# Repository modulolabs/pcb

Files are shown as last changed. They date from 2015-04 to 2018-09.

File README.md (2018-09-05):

Modulo PCBs
===

This repository contains modulo circuit board schematics and pcb layouts.

Repository Contents
---

* Base/ - Eagle files for the Modulo Base
* Controller/ - Eagle files for the Modulo Controller
* Display/ - Eagle files for the Modulo Display
* Eagle/ - Common eagle files and libraries
* IRRemote/ - Eagle files for the Modulo IR Transceiver
* Joystick/ - Eagle files for the Modulo Joystick
* Knob/ - Eagle files for the Modulo Knob
* MotorDriver/ - Eagle files for Modulo Motor Driver
* Panel/ - Scripts for combining individual eagle boards into panels
* ParticleBase/ - Eagle files for the Modulo Particle Base
* Programmer/ - Eagle files for a board that's used to program other modulo boards
* TempProbe/ - Eagle files for the Modulo Temp Probe

Export
---

To export data for manufacturing:

* Load and run Eagle/Modulo.cam from the eagle cam processor. This will generate files in <Board>/Modulo<Board>RFQ/
* Run the ulp moundsmd.ulp and save the mount files to the same RFQ directory
* Run Eagle/integer-bom.ulp to generate the bom file and save it to the same RFQ directory.

License Information
-------------------
These circuit board designs are release under  [Creative Commons ShareAlike 4.0 International](https://creativecommons.org/licenses/by-sa/4.0/).

Please use, reuse, and modify these files as you see fit. Please maintain attribute to Modulo Labs LLC and release derivative work under the same license.

Distributed as-is; no warranty is given.

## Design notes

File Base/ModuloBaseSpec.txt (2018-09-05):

PCB: .062” (1.6mm) FR4 Lead Free RoHS compliant
Layers: 2
Copper: 1oz
Soldermask: Purple
Silkscreen: White
ENIG
SMD both sides
PTH one side

Space jumpers off of PCB using provided spacers before PTH soldering
Manually attach adhesive rubber feet
Snap in card guides

RoHS compliant assembly
Program mcu using provided jig and atmel studio software
Test board using provided jig and testing procedure

Package board in static shielding bag
Print provided label and apply to bag.
Package in cartons of qty 50 with provided carton label.

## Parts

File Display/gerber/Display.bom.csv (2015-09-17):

Qty | Value | Device | Package | Parts | Description | BOARD | BOM | MANUFACTURER | PARTNUM | SUPPLIER | VALUE | VERSION
2 | .1uF | CAPACITOR-.1UF | 0603 | C3, C6 | Capacitor |  |  |  | C0603C104K5RACTU |  | .1uF
1 | 1.33M | RESISTOR-0603 | 0603 | R2 | Resistor |  |  |  | ERJ-3EKF1304V
1 | 10K | RESISTOR-10KΩ | 0603 | R1 | Resistor |  |  |  | ERJ-3EKF1002V |  | 10KΩ
3 | 10KΩ | RESISTOR-10KΩ | 0603 | R3, R5, R6 | Resistor |  |  |  | ERJ-3EKF1002V |  | 10KΩ
4 | 10uF | CAPACITOR-10UF | 0603 | C1, C2, C4, C5 | Capacitor |  |  |  | GRM188R61C106MA73D |  | 10uF
1 | 10uH | INDUCTOR | INDUCTOR_1007 | L1 | Inductors |  |  |  | MPI2520R1-100-R
2 | 1KΩ | RESISTOR-1KΩ | 0603 | R4, R7 | Resistor |  |  |  | ERJ-3EKF1001V |  | 1KΩ
1 | ATSAMD20E17A-AU | SAMD21E | TQFP-32 | U3 |  |  |  |  | ATSAMD20E17A-AU |  | ATSAMD21E18A-AU
1 | BAT54T1G | DIODE-SCHOTTKY | SMP | D1 |  |  |  |  | SS3P3-M3/84A
1 | DEVICE-PCB | DEVICE-PCB | DEVICE-PCB | PCB1 | Modulo Footprint | Display |  |  | Display PCB |  |  | 4
1 | ER-OLED0.95-2C | OLED-COLORREVERSE | FPC-24-REVERSE | U1 |  |  |  | buydisplay.com | ER-OLED0.95-2C | buydisplay.com | ER-OLED0.95-2C
1 | FAN5331SX | FAN5331 | SOT23-5 | U2 | FAN5331 - LED/OLED 20V Boost Converter |  |  |  | FAN5331SX
1 | HEADER-1X4-AMPMODU | HEADER-1X4-AMPMODU | AMPMODU-4P | JP2 |  |  |  |  | 147721-3
1 | MIC5205-3.3YM5 TR | VREG-MIC5205-3.3V | SOT23-5 | U4 | V_REG MIC5219 |  |  |  | MIC5205-3.3YM5 TR |  | MIC5205-3.3YM5 TR
3 | SWITCH-PTS-810 | SWITCH-PTS-810 | TACT-SWITCH-PTS-810 | SW1, SW2, SW3 |  |  |  |  | PTS810 SJM 250 SMTR LFS
1 | blue | LED-0805-BLUE | 0805-LED | LED1 | LED |  |  |  | LTST-C171TBKT |  | blue

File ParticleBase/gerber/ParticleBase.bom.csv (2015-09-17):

Qty | Value | Device | Package | Parts | Description | BOM | NOBOM | PARTNUM | VALUE
1 |  | BOM_ITEM |  | BOM5 |  |  |  | Particle Base PCB
4 |  | M04LOCK | 1X04_LOCK | JP1, JP3, JP5, JP6 | Header 4 |  |  | M20-9750446
1 | 10uF | CAPACITOR-10UF | 0603 | C2 | Capacitor |  |  | GRM188R61C106MA73D | 10uF
2 | 12Ω | RESISTOR-12Ω | 0603 | R3, R4 | Resistor |  |  | ERJ-PA3J120V | 12Ω
1 | 56uF | CAPACITOR-POL-56UF-25V | PANASONIC_D | C1 |  |  |  | EMVA250ADA560MF55G | 56uF
2 | 5kΩ | RESISTOR-5KΩ | 0603 | R1, R2 | Resistor |  |  | ERJ-3EKF5101V | 5kΩ
2 | CARD-GUIDE | CARD-GUIDE | CARD-GUIDE-2 | G1, G3 |  |  |  | HCG-201-165
1 | CARD-GUIDE | CARD-GUIDE | CARD-GUIDE-2 | G2 |  |  |  | HCG-202-165
2 | HEADER-2X18 | HEADER-2X18 | 2X18-LOCK | JP8, JP9 |  |  |  | 12x2 Receptacle
3 | HEADER-MODULO | HEADER-MODULO | JST-PA-SIDE-SMD | JP2, JP4, JP7 |  |  |  | 4P-SMD-2.0-90D
2 | RB751V40 | DIODE-SCHOTTKY-BAT60A | SOD-323 | D1, D2 |  |  |  | RB751V40
1 | SOLDERJUMPERNO | SOLDERJUMPERNO | SJ_2S-NO | SJ1 | Solder Jumper
1 | VREG-MIC5205-3.3V | VREG-MIC5205-3.3V | SOT23-5 | U1 | V_REG MIC5219 |  |  | MIC5205-3.3YM5 TR
4 | foot | BOM_ITEM |  | BOM1, BOM2, BOM3, BOM4 |  |  |  | SJ61A4

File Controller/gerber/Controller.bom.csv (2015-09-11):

Qty | Value | Device | Package | Parts | Description | BOM | PARTNUM | VALUE
3 |  | PINHD-1X6LOCK | 1X06-BIGLOCK | JP3, JP4, JP5 | PIN HEADER |  | M20-9990646
3 | .1uF | CAPACITOR-.1UF | 0603 | C4, C7, C8 | Capacitor |  | C0603C104K5RACTU | .1uF
3 | 10uF | CAPACITOR-10UF | 0603 | C1, C6, C9 | Capacitor |  | GRM188R61C106MA73D | 10uF
1 | 10uH | INDUCTOR-10UH | 0603 | L1 |  |  | BLM18TG102TN1D | 10uH
2 | 18pF | CAPACITOR-18PF | 0603 | C2, C3 | Capacitor |  | C0603C180J5GACTU | 18pF
2 | 1KΩ | RESISTOR-1KΩ | 0603 | R9, R10 | Resistor |  | ERJ-3EKF1001V | 1KΩ
6 | 470Ω | RESISTOR-470Ω | 0603 | R3, R4, R5, R6, R7, R8 | Resistor |  | ERJ-3EKF4700V | 470Ω
1 | 56uF | CAPACITOR-POL-56UF-25V | PANASONIC_D | C5 |  |  | EMVA250ADA560MF55G | 56uF
2 | 5kΩ | RESISTOR-5KΩ | 0603 | R1, R2 | Resistor |  | ERJ-3EKF5101V | 5kΩ
1 | ATSAMD21E18A-AU | SAMD21E | TQFP-32 | U1 |  |  | ATSAMD21E18A-AUT | ATSAMD21E18A-AU
1 | CRYSTAL-AB26TRQ-32.768K | CRYSTAL-AB26TRQ-32.768K | CRYSTAL-AB26TRQ | X1 |  |  | AB26TRQ-32.768KHZ-T
1 | DEVICE-PCB | DEVICE-PCB | DEVICE-PCB | PCB1 | Modulo Footprint |  | Controller PCB
1 | DIODE-SCHOTTKY | DIODE-SCHOTTKY | SMP | D1 |  |  | SS3P3-M3/84A
6 | DIODE-SCHOTTKY-BAT60A | DIODE-SCHOTTKY-BAT60A | SOD-323 | D2, D3, D4, D5, D6, D7 |  |  | RB751V40
1 | HEADER-1X4-AMPMODU | HEADER-1X4-AMPMODU | AMPMODU-4P | JP2 |  |  | 147721-3
1 | M02LOCK | M02LOCK | 1X02_LOCK | JP6 | Standard 2-pin 0.1 header. Use with" |  | M20-9990246
1 | SWITCH-PTS-810 | SWITCH-PTS-810 | TACT-SWITCH-PTS-810 | SW1 |  |  | PTS810 SJM 250 SMTR LFS
1 | USBFCI-MICROB | USBFCI-MICROB | USB-MICROB-FCI | JP1 |  |  | 10118193-0001LF
1 | VREG-MIC5205-3.3V | VREG-MIC5205-3.3V | SOT23-5 | U2 | V_REG MIC5219 |  | MIC5205-3.3YM5 TR
1 | blue | LED-0805-BLUE | 0805-LED | LED1 | LED |  | LTST-C171KRKT | blue
1 | blue | LED-0805-BLUE | 0805-LED | LED2 | LED |  | LTST-C171TBKT | blue

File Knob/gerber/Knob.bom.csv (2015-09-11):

Qty | Value | Device | Package | Parts | Description | BOM | PARTNUM | VALUE
1 | .1uF | CAPACITOR-.1UF | 0603 | C1 | Capacitor |  | C0603C104K5RACTU | .1uF
2 | 0Ω | RESISTOR-0Ω | 0603 | R8, R9 | Resistor |  | ERJ-3GEY0R00V | 0Ω
6 | 150Ω | RESISTOR-150Ω | 0603 | R2, R3, R4, R5, R6, R10 | Resistor |  | ERJ-3EKF1500V | 150Ω
2 | 1KΩ | RESISTOR-1KΩ | 0603 | R1, R7 | Resistor |  | ERJ-3EKF1001V | 1KΩ
1 | ATTINY841 | ATTINY841 | SOIC-14 | U2 |  |  | ATTINY841-SSUR
1 | BOM_ITEM | BOM_ITEM |  | CAP1 |  |  | Knob Cap
1 | DEVICE-PCB | DEVICE-PCB | DEVICE-PCB | PCB1 | Modulo Footprint |  | Knob PCB
1 | HEADER-1X4-AMPMODU | HEADER-1X4-AMPMODU | AMPMODU-4P | JP1 |  |  | 147721-3
1 | LED-1206-REV | LED-1206-REV | LED-1206-REV | LED1 | LED |  | LTST-C230TBKT
1 | TopUp EC12PLRGBSDVBF-D | ENCODER_RGB_CASIDEPADS | ENCODER_LED_3_SIDEPADS | SW1 | Illuminated Rotary Encoder w/ RGB LED and select switch |  | TopUp EC12PLRGBSDVBF-D

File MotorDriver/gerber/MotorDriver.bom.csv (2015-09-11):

Qty | Value | Device | Package | Parts | Description | BOM | PARTNUM | RATING | VALUE
1 |  | M03LOCK_NO_SILK | 1X03_LOCK_NO_SILK | JP2 | Header 3 |  | M20-9990346
1 |  | M063.5MM-6 | SCREWTERMINAL-3.5MM-6 | JP3 | Header 6 |  | OSTTE060104
1 | .1uF | CAPACITOR-.1UF | 0603 | C1 | Capacitor |  | C0603C104K5RACTU |  | .1uF
1 | .1uF | CAPACITOR-.1UF | 0603 | C2 | Capacitor |  | C0603C104K5RACTU | >20V | .1uF
2 | .25Ω | RESISTOR2010 | R2010 | R3, R4 | Resistor |  | CSRN2010FKR250
2 | 0Ω | RESISTOR-0Ω | 0603 | R12, R13 | Resistor |  | ERJ-3GEY0R00V |  | 0Ω
1 | 10uF | CAPACITOR-10UF | 0603 | C4 | Capacitor |  | GRM188R61C106MA73D |  | 10uF
1 | 1KΩ | RESISTOR-1KΩ | 0603 | R1 | Resistor |  | ERJ-3EKF1001V |  | 1KΩ
1 | 56uF | CAPACITOR-POL-56UF-25V | PANASONIC_D | C3 |  |  | EMVA250ADA560MF55G | >20V | 56uF
1 | ATTINY841 | ATTINY841 | SOIC-14 | U3 |  |  | ATTINY841-SSUR
1 | DEVICE-PCB | DEVICE-PCB | DEVICE-PCB | PCB1 | Modulo Footprint |  | Motor Driver PCB
1 | DIODE-SCHOTTKY | DIODE-SCHOTTKY | SMP | D1 |  |  | SS3P3-M3/84A
1 | DRV8848 | DRV8848 | HTSSOP-16 | U2 |  |  | DRV8848PWP
1 | HEADER-1X4-AMPMODU | HEADER-1X4-AMPMODU | AMPMODU-4P | JP1 |  |  | 147721-3
1 | MCP4013 | MCP4013 | SOT-23-6 | U1 |  |  | MCP4013T-503E/CH
1 | RB751V40 | DIODE-SCHOTTKY-BAT60A | SOD-323 | D2 |  |  | RB751V40
1 | blue | LED-0805-BLUE | 0805-LED | LED1 | LED |  | LTST-C171TBKT |  | blue
1 | shunt | BOM_ITEM |  | SHUNT1 |  |  | SPC02SYAN

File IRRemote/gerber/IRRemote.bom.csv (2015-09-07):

Qty | Value | Device | Package | Parts | Description | BOM | PARTNUM | VALUE
1 |  | LED5MM | LED5MM | LED2 | LEDs |  | IR928-6C-F
1 | .1uF | CAPACITOR-.1UF | 0603 | C1 | Capacitor |  | C0603C104K5RACTU | .1uF
5 | 150Ω | RESISTOR-150Ω | 0603 | R2, R3, R4, R5, R6 | Resistor |  | ERJ-3EKF1500V | 150Ω
1 | 1KΩ | RESISTOR-1KΩ | 0603 | R1 | Resistor |  | ERJ-3EKF1001V | 1KΩ
1 | ATTINY841 | ATTINY841 | SOIC-14 | U3 |  |  | ATTINY841-SSUR
1 | DEVICE-PCB | DEVICE-PCB | DEVICE-PCB | PCB1 | Modulo Footprint |  | IRRemote PCB
1 | HEADER-1X4-AMPMODU | HEADER-1X4-AMPMODU | AMPMODU-4P | JP1 |  |  | 147721-3
1 | LED-1206-REV | LED-1206-REV | LED-1206-REV | LED1 | LED |  | LTST-C230TBKT
1 | PNA460XM | PNA460XM | PNA460XM | U1 | IR 38KHz receiver |  | TSOP38338

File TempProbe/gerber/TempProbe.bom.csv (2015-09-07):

Qty | Value | Device | Package | Parts | Description | BOM | PARTNUM | VALUE
2 | .1uF | CAPACITOR-.1UF | 0603 | C1, C2 | Capacitor |  | C0603C104K5RACTU | .1uF
1 | 10KΩ | RESISTOR-10KΩ | 0603 | R1 | Resistor |  | ERJ-3EKF1002V | 10KΩ
1 | 1KΩ | RESISTOR-1KΩ | 0603 | R2 | Resistor |  | ERJ-3EKF1001V | 1KΩ
1 | ATTINY841 | ATTINY841 | SOIC-14 | U2 |  |  | ATTINY841-SSUR
1 | BOM_ITEM | BOM_ITEM |  | HS1 |  |  | F221B1/2 CL210
1 | BOM_ITEM | BOM_ITEM |  | PCB1 |  |  | Temp Probe PCB
1 | TEMP-PROBE | TEMP-PROBE | TEMP_PROBE | PROBE1 |  |  | NTCLE413E2103F102L
1 | blue | LED-0805-BLUE | 0805-LED | LED1 | LED |  | LTST-C171TBKT | blue

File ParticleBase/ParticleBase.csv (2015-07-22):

Qty | Value | Device | Package | Parts | Description | BOM | NOBOM | PARTNUM | VALUE
1 |  | BOM_ITEM |  | BOM5 |  |  |  | Particle Base PCB
4 |  | M04LOCK | 1X04_LOCK | JP1, JP3, JP5, JP6 | Header 4 |  |  | M20-9750446
2 | 1KΩ | RESISTOR-1KΩ | 0603 | R1, R2 | Resistor |  |  | ERJ-3EKF1001V | 1KΩ
1 | 56uF | CAPACITOR-POL-56UF-25V | PANASONIC_D | C1 |  |  |  | EMVA250ADA560MF55G | 56uF
2 | CARD-GUIDE | CARD-GUIDE | CARD-GUIDE-2 | G1, G3 |  |  |  | HCG-201-165
1 | CARD-GUIDE | CARD-GUIDE | CARD-GUIDE-2 | G2 |  |  |  | HCG-202-165
3 | HEADER-1X4-JST-PA-SIDE-SMD | HEADER-1X4-JST-PA-SIDE-SMD | JST-PA-SIDE-SMD | JP2, JP4, JP7 |  |  |  | SM04B-PASS-TBT(LF)(SN)
2 | HEADER-2X18 | HEADER-2X18 | 2X18-LOCK | JP8, JP9 |  |  |  | PPTC182LFBN-RC
4 | foot | BOM_ITEM |  | BOM1, BOM2, BOM3, BOM4 |  |  |  | SJ61A4

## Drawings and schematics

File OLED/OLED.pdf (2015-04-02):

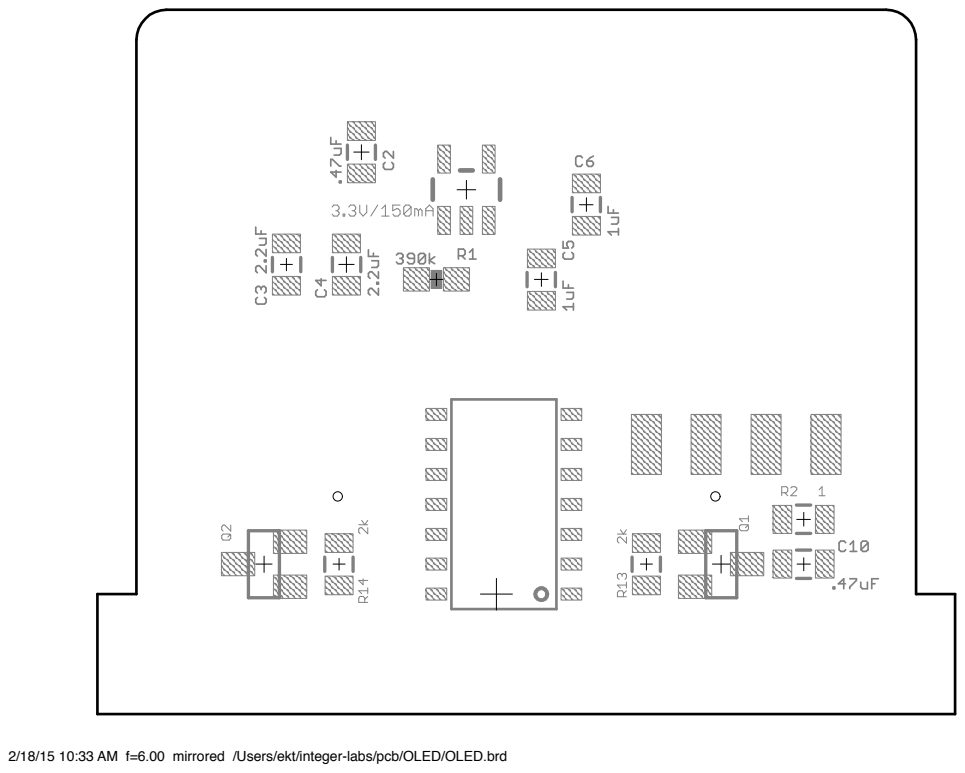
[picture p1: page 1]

2/18/15 10:33 AM f=6.00 mirrored /Users/ekt/integer-labs/pcb/OLED/OLED.brd

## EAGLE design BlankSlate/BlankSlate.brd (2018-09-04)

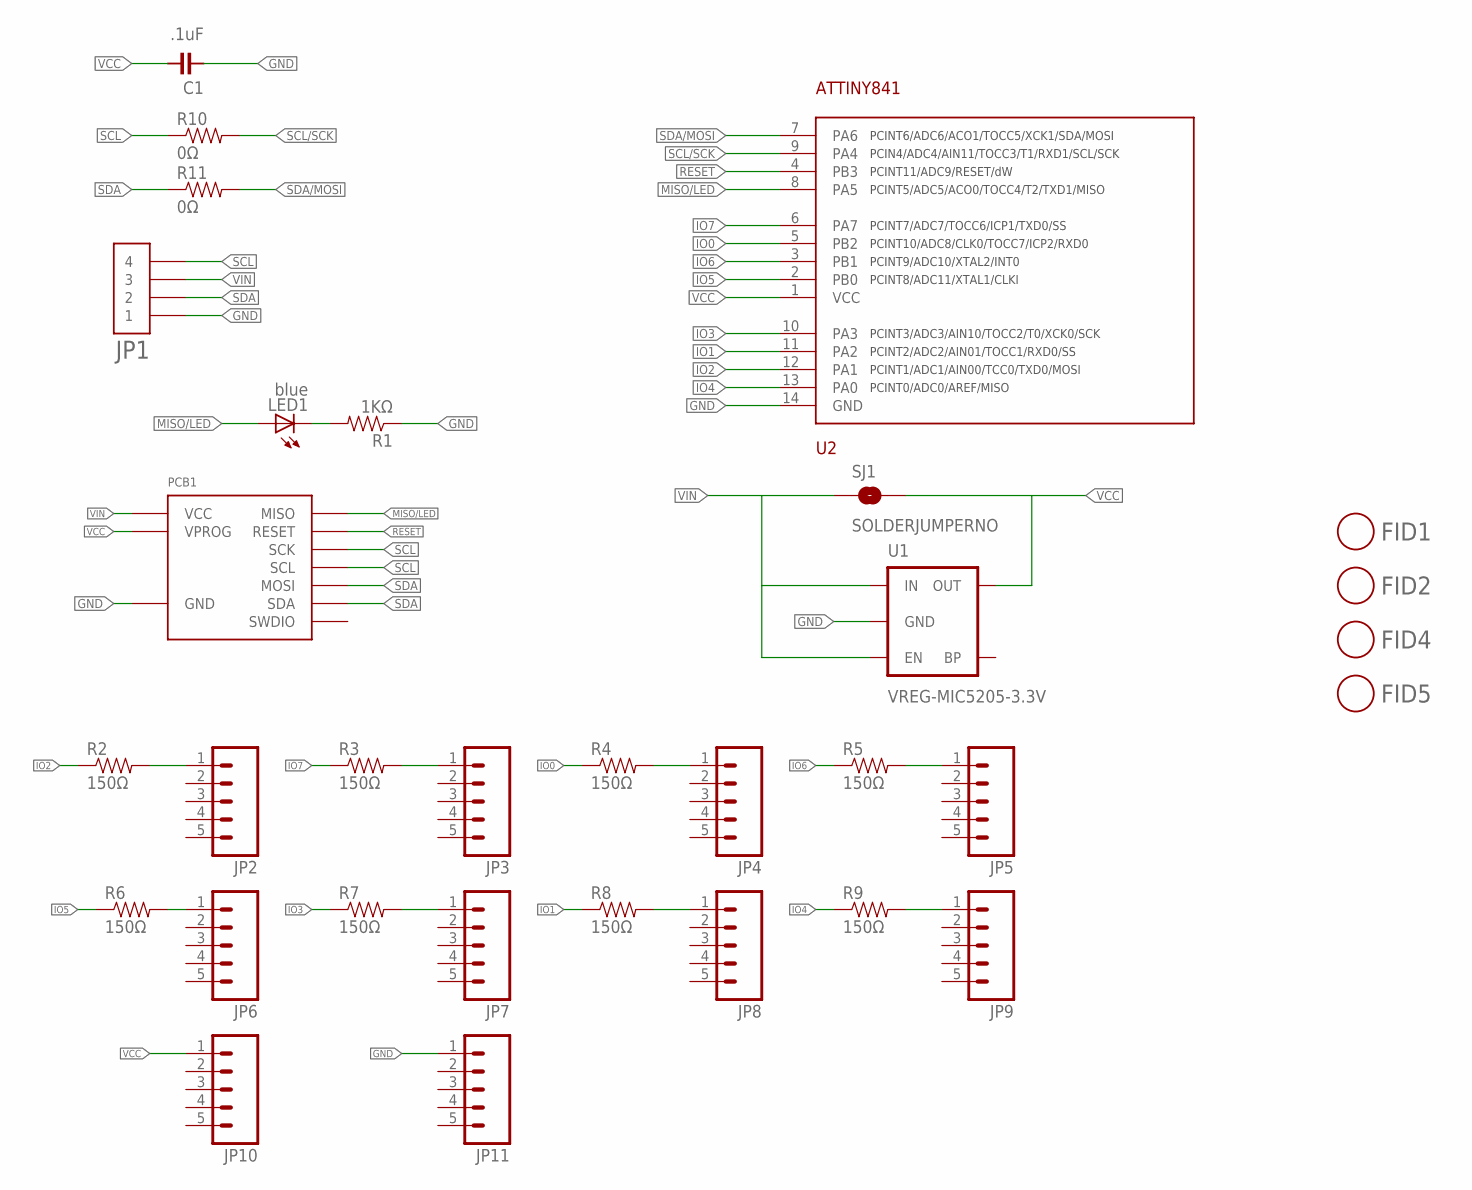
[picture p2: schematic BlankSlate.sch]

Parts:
C1: .1uF; 0603
FID1, FID2, FID4, FID5: FIDUCIAL; FIDUCIAL_1MM
JP1: HEADER-1X4-AMPMODU; AMPMODU-4P
JP2, JP3, JP4, JP5, JP6, JP7, JP8, JP9, JP10, JP11: M05NO_SILK; 1X05_NO_SILK; PARTNUM EXCLUDE
LED1: blue; 0805-LED
PCB1: DEVICE-PCB; PARTNUM Blank Slate PCB
R1: 1KΩ; 0603
R2, R3, R4, R5, R6, R7, R8, R9: 150Ω; 0603
R10, R11: 0Ω; 0603
SJ1: SOLDERJUMPERNO; SJ_2S-NO
U1: VREG-MIC5205-3.3V; SOT23-5
U2: ATTINY841; SOIC-14

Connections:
GND: C1.2, JP1.P$1 (1), JP1.P$2 (1), JP11.1, PCB1.GND, R1.1, U1.2 (GND), U2.14 (GND)
IO0: R4.1, U2.5 (PB2)
IO1: R8.1, U2.11 (PA2)
IO2: R2.1, U2.12 (PA1)
IO3: R7.1, U2.10 (PA3)
IO4: R9.1, U2.13 (PA0)
IO5: R6.1, U2.2 (PB0)
IO6: R5.1, U2.3 (PB1)
IO7: R3.1, U2.6 (PA7)
MISO/LED: LED1.A, PCB1.MISO, U2.8 (PA5)
unnamed: JP4.1, R4.2
unnamed: JP5.1, R5.2
unnamed: JP7.1, R7.2
unnamed: JP2.1, R2.2
unnamed: JP3.1, R3.2
unnamed: JP6.1, R6.2
unnamed: JP9.1, R9.2
unnamed: LED1.C, R1.2
unnamed: JP8.1, R8.2
RESET: PCB1.RESET, U2.4 (PB3)
SCL: JP1.P$7 (4), JP1.P$8 (4), PCB1.CLK (SCK), PCB1.SCL, R10.1
SCL/SCK: R10.2, U2.9 (PA4)
SDA: JP1.P$3 (2), JP1.P$4 (2), PCB1.MOSI, PCB1.SDA, R11.1
SDA/MOSI: R11.2, U2.7 (PA6)
VCC: C1.1, JP10.1, PCB1.VPROG, SJ1.2, U1.5 (OUT), U2.1 (VCC)
VIN: JP1.P$5 (3), JP1.P$6 (3), PCB1.VCC, SJ1.1, U1.1 (IN), U1.3 (EN)

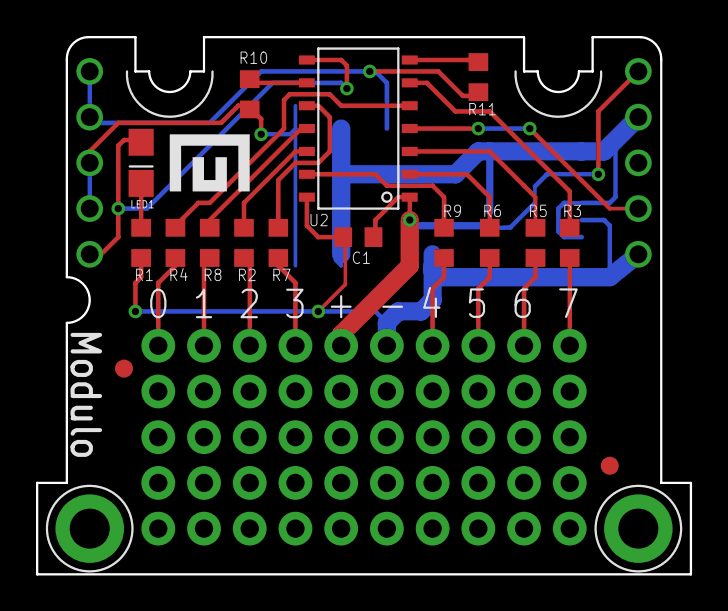
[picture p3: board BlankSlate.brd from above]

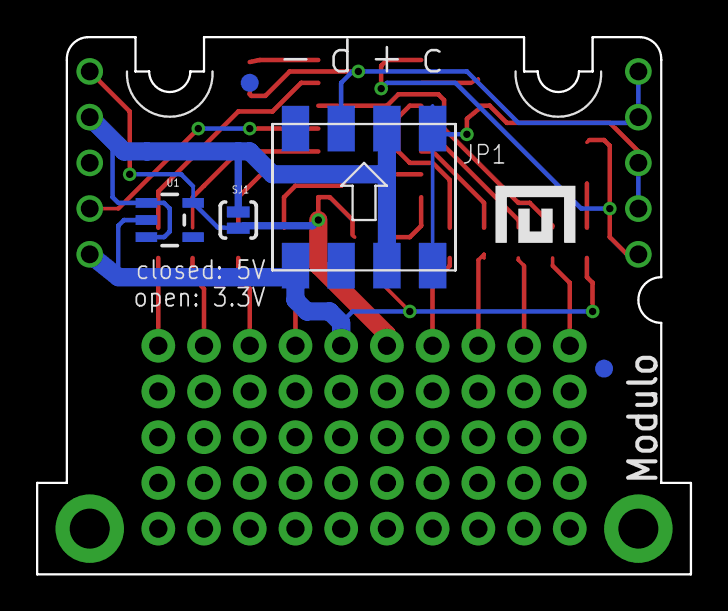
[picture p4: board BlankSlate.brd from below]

Board: 2 copper layers, 36.3 x 29.8 mm, 34 parts (16 on the bottom side), 26 nets.

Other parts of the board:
U$1, U$2: LOGO-SMALL

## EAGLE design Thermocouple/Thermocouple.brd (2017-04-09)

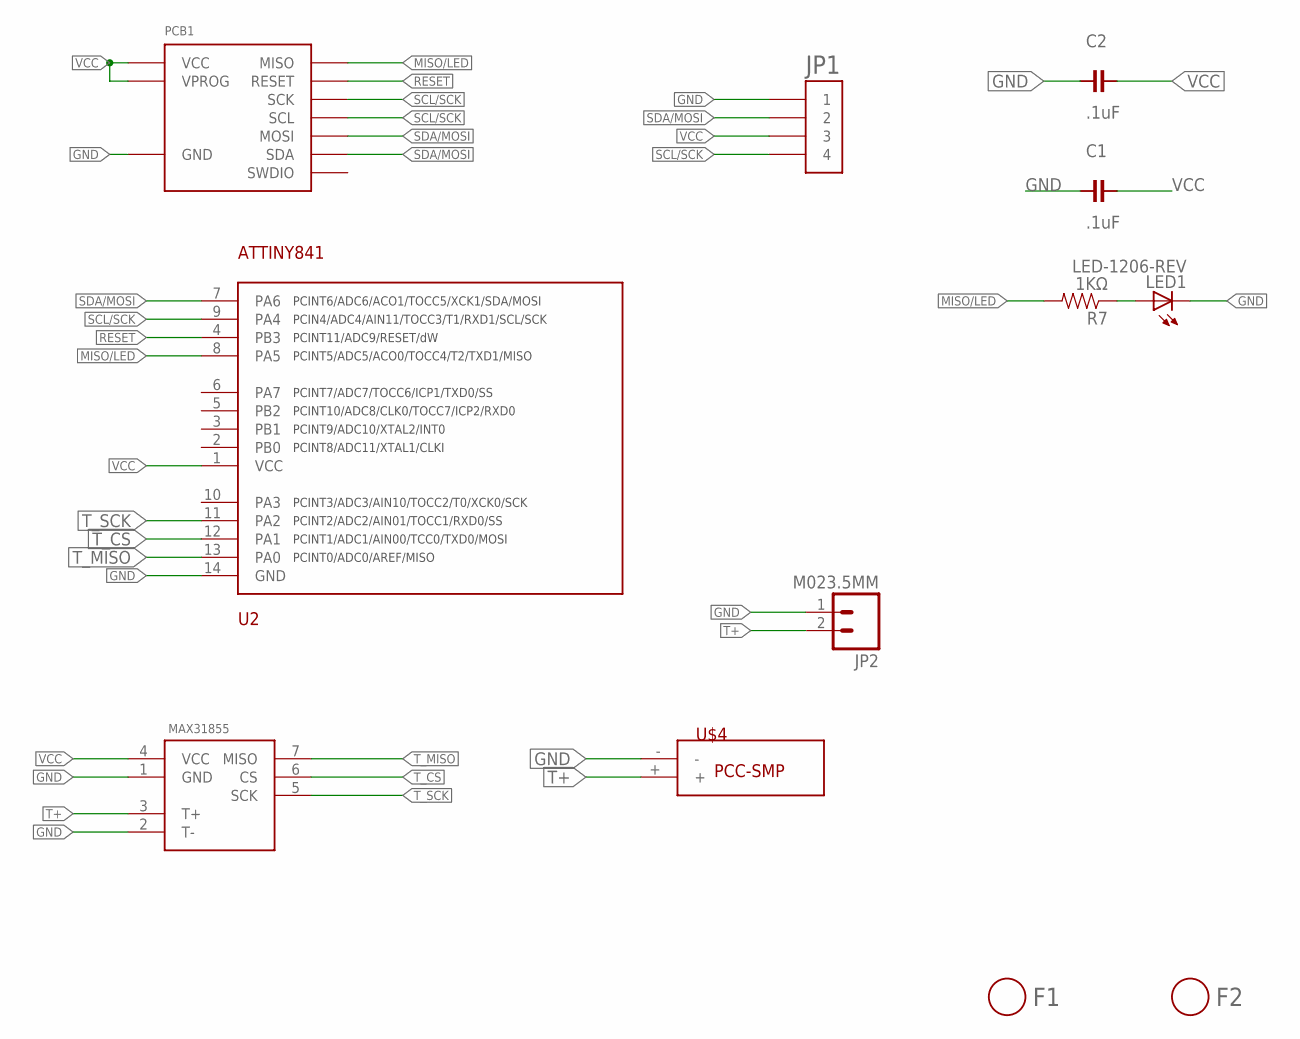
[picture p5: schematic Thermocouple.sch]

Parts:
C1, C2: .1uF; 0603
F1, F2: FIDUCIAL; FIDUCIAL_1MM
JP1: HEADER-1X4-AMPMODU; AMPMODU-4P
JP2: M023.5MM; SCREWTERMINAL-3.5MM-2
LED1: LED-1206-REV
PCB1: DEVICE-PCB; PARTNUM Therm PCB
R7: 1KΩ; 0603
U2: ATTINY841; SOIC-14
U$4: PCC-SMP
U$5: MAX31855; SOIC-8

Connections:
GND: C1.2, C2.2, JP1.P$1 (1), JP1.P$2 (1), JP2.1, LED1.C, PCB1.GND, U2.14 (GND), U$4.-, U$5.1 (GND), U$5.2 (T-)
MISO/LED: PCB1.MISO, R7.2, U2.8 (PA5)
unnamed: LED1.A, R7.1
RESET: PCB1.RESET, U2.4 (PB3)
SCL/SCK: JP1.P$7 (4), JP1.P$8 (4), PCB1.CLK (SCK), PCB1.SCL, U2.9 (PA4)
SDA/MOSI: JP1.P$3 (2), JP1.P$4 (2), PCB1.MOSI, PCB1.SDA, U2.7 (PA6)
T+: JP2.2, U$4.+, U$5.3 (T+)
T_CS: U2.12 (PA1), U$5.6 (CS)
T_MISO: U2.13 (PA0), U$5.7 (MISO)
T_SCK: U2.11 (PA2), U$5.5 (SCK)
VCC: C1.1, C2.1, JP1.P$5 (3), JP1.P$6 (3), PCB1.VCC, PCB1.VPROG, U2.1 (VCC), U$5.4 (VCC)

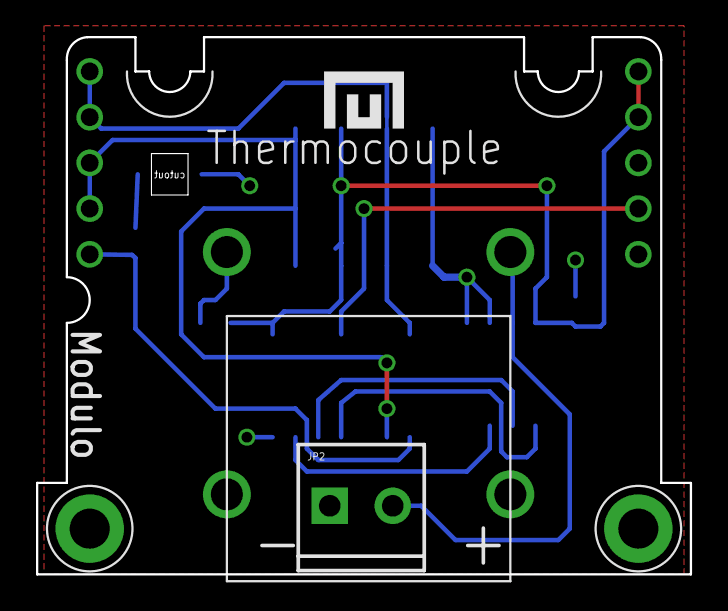
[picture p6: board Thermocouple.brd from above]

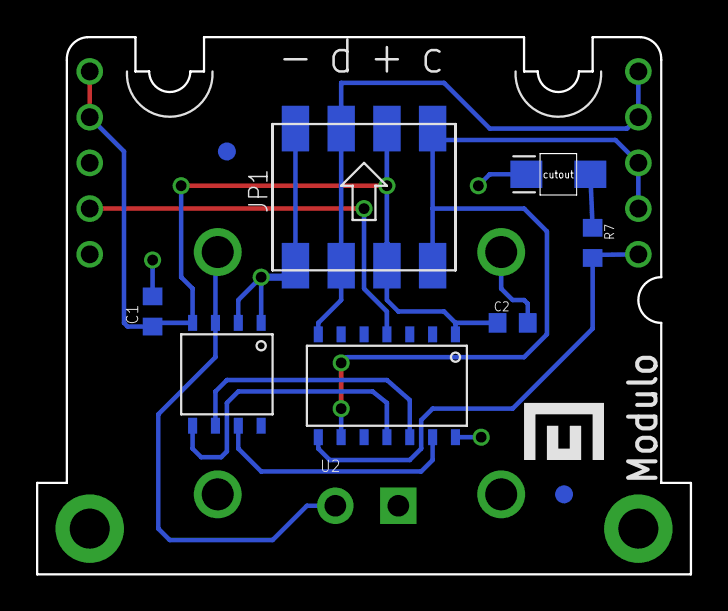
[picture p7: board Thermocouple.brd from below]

Board: 2 copper layers, 36.3 x 29.8 mm, 14 parts (10 on the bottom side), 11 nets.

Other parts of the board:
U$2, U$3: LOGO-SMALL

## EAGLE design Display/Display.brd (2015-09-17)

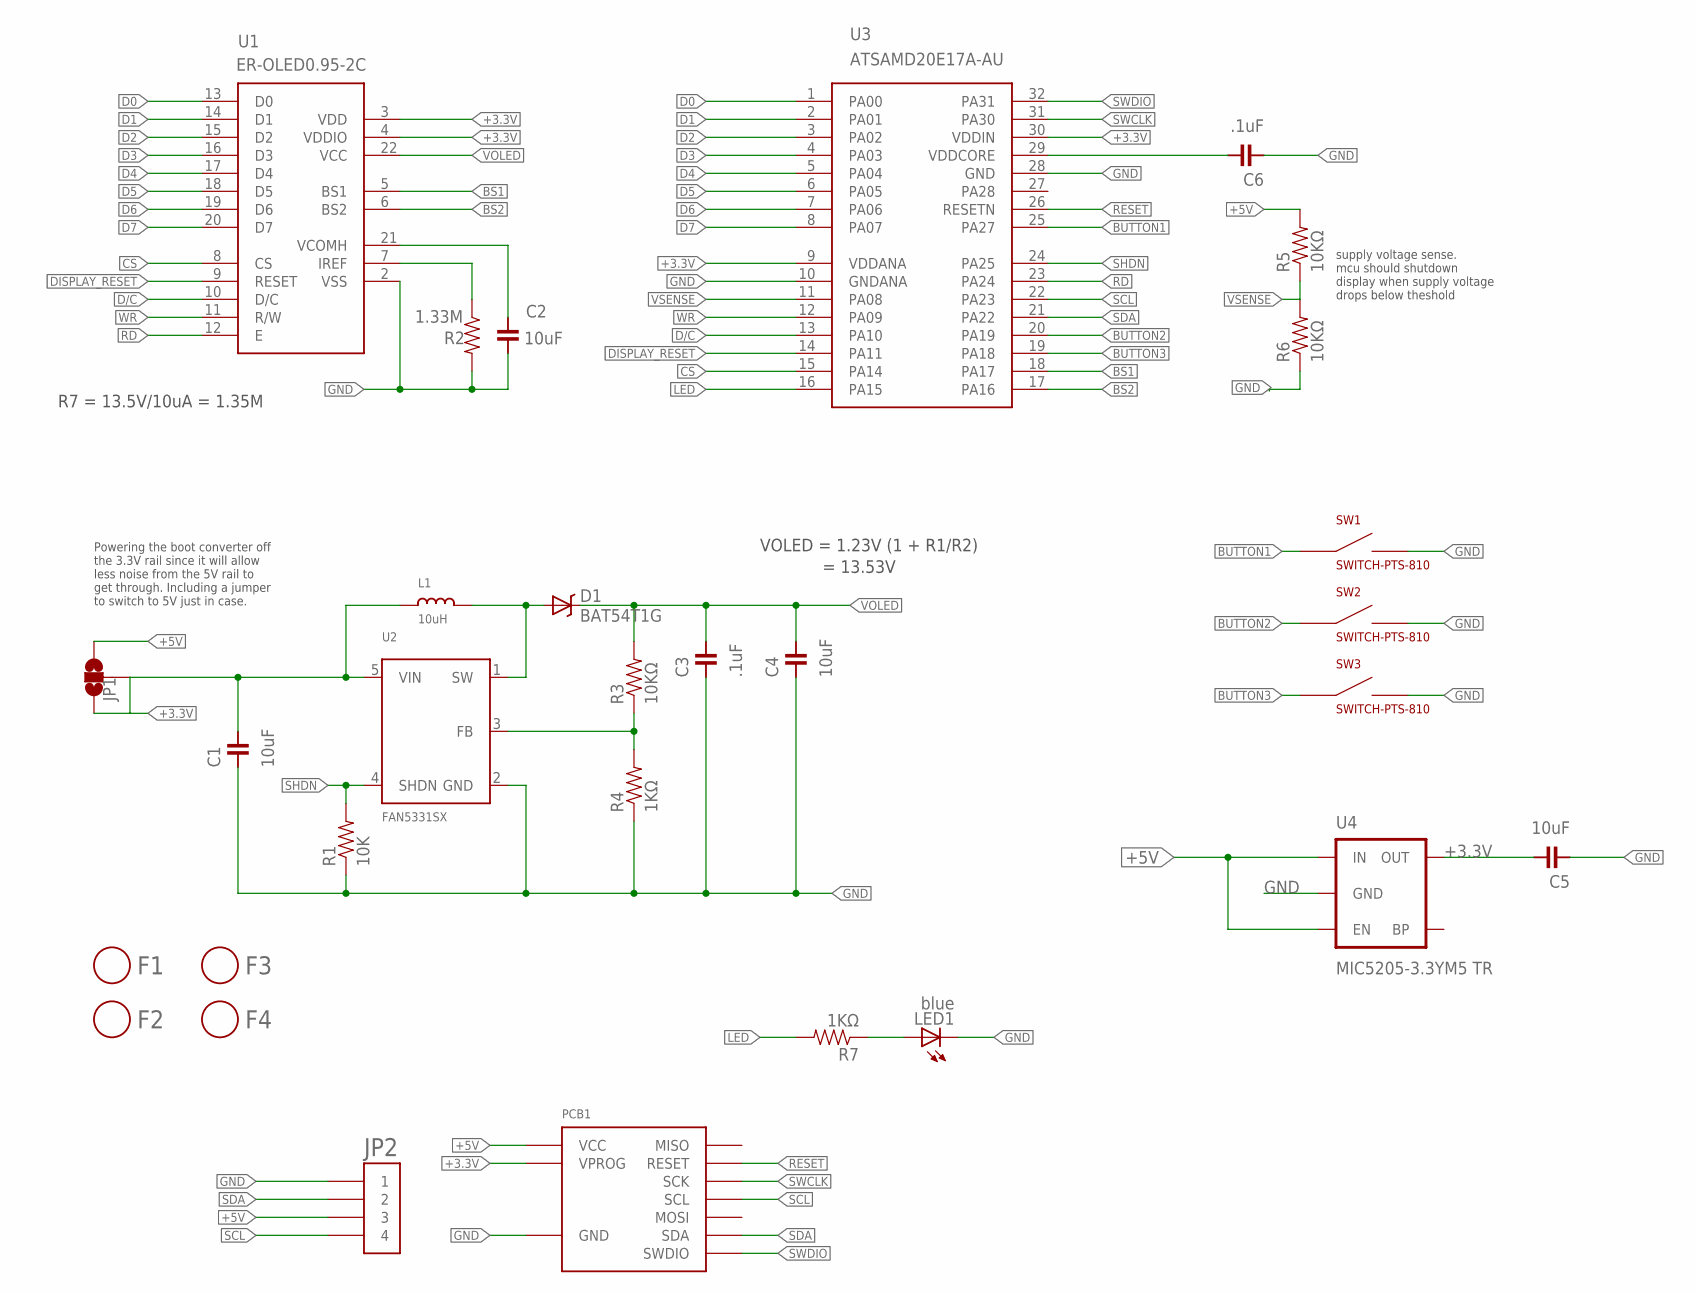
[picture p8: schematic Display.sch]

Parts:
C1, C2, C4, C5: 10uF; 0603
C3, C6: .1uF; 0603
D1: BAT54T1G; SMP
F1, F2, F3, F4: FIDUCIAL; FIDUCIAL_1MM
JP1: SOLDERJUMPER_2WAYS; SJ_3
JP2: HEADER-1X4-AMPMODU; AMPMODU-4P
L1: 10uH; INDUCTOR_1007; PARTNUM MPI2520R1-100-R
LED1: blue; 0805-LED
PCB1: DEVICE-PCB; PARTNUM Display PCB
R1: 10K; 0603
R2: 1.33M; 0603; PARTNUM ERJ-3EKF1304V
R3, R5, R6: 10KΩ; 0603
R4, R7: 1KΩ; 0603
SW1, SW2, SW3: SWITCH-PTS-810; TACT-SWITCH-PTS-810
U1: ER-OLED0.95-2C; FPC-24-REVERSE; PARTNUM ER-OLED0.95-2C
U2: FAN5331SX; SOT23-5; PARTNUM FAN5331SX
U3: ATSAMD20E17A-AU; TQFP-32; PARTNUM ATSAMD20E17A-AU
U4: MIC5205-3.3YM5 TR; SOT23-5; PARTNUM MIC5205-3.3YM5 TR

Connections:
+3.3V: C1.1, C5.1, JP1.1, JP1.2, L1.P$1 (1), PCB1.VPROG, U1.3 (VDD), U1.4 (VDDIO), U2.5 (VIN), U3.9 (VDDANA), U3.30 (VDDIN), U4.5 (OUT)
+5V: JP1.3, JP2.P$5 (3), JP2.P$6 (3), PCB1.VCC, R5.2, U4.1 (IN), U4.3 (EN)
BS1: U1.5 (BS1), U3.18 (PA17)
BS2: U1.6 (BS2), U3.17 (PA16)
BUTTON1: SW1.P$1 (POS1), SW1.P$2 (POS1), U3.25 (PA27)
BUTTON2: SW2.P$1 (POS1), SW2.P$2 (POS1), U3.20 (PA19)
BUTTON3: SW3.P$1 (POS1), SW3.P$2 (POS1), U3.19 (PA18)
CS: U1.8 (CS), U3.15 (PA14)
D0: U1.13 (D0), U3.1 (PA00)
D1: U1.14 (D1), U3.2 (PA01)
D2: U1.15 (D2), U3.3 (PA02)
D3: U1.16 (D3), U3.4 (PA03)
D4: U1.17 (D4), U3.5 (PA04)
D5: U1.18 (D5), U3.6 (PA05)
D6: U1.19 (D6), U3.7 (PA06)
D7: U1.20 (D7), U3.8 (PA07)
D/C: U1.10 (D/C), U3.13 (PA10)
DISPLAY_RESET: U1.9 (RESET), U3.14 (PA11)
GND: C1.2, C2.2, C3.2, C4.2, C5.2, C6.2, JP2.P$1 (1), JP2.P$2 (1), LED1.C, PCB1.GND, R1.1, R2.2, R4.1, R6.1, SW1.P$3 (NEG1), SW1.P$4 (NEG1), SW2.P$3 (NEG1), SW2.P$4 (NEG1), SW3.P$3 (NEG1), SW3.P$4 (NEG1), U1.2 (VSS), U2.2 (GND), U3.10 (GNDANA), U3.28 (GND), U4.2 (GND)
LED: R7.2, U3.16 (PA15)
unnamed: D1.A, L1.P$2 (2), U2.1 (SW)
unnamed: R3.1, R4.2, U2.3 (FB)
unnamed: C6.1, U3.29 (VDDCORE)
unnamed: C2.1, U1.21 (VCOMH)
unnamed: LED1.A, R7.1
unnamed: R2.1, U1.7 (IREF)
RD: U1.12 (E), U3.23 (PA24)
RESET: PCB1.RESET, U3.26 (RESETN)
SCL: JP2.P$7 (4), JP2.P$8 (4), PCB1.SCL, U3.22 (PA23)
SDA: JP2.P$3 (2), JP2.P$4 (2), PCB1.SDA, U3.21 (PA22)
SHDN: R1.2, U2.4 (SHDN), U3.24 (PA25)
SWCLK: PCB1.CLK (SCK), U3.31 (PA30)
SWDIO: PCB1.SWDIO, U3.32 (PA31)
VOLED: C3.1, C4.1, D1.C, R3.2, U1.22 (VCC)
VSENSE: R5.1, R6.2, U3.11 (PA08)
WR: U1.11 (R/W), U3.12 (PA09)

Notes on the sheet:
VOLED = 1.23V (1 + R1/R2)
= 13.53V
R7 = 13.5V/10uA = 1.35M
supply voltage sense. mcu should shutdown display when supply voltage drops below theshold
Powering the boot converter off the 3.3V rail since it will allow less noise from the 5V rail to get through. Including a jumper to switch to 5V just in case.

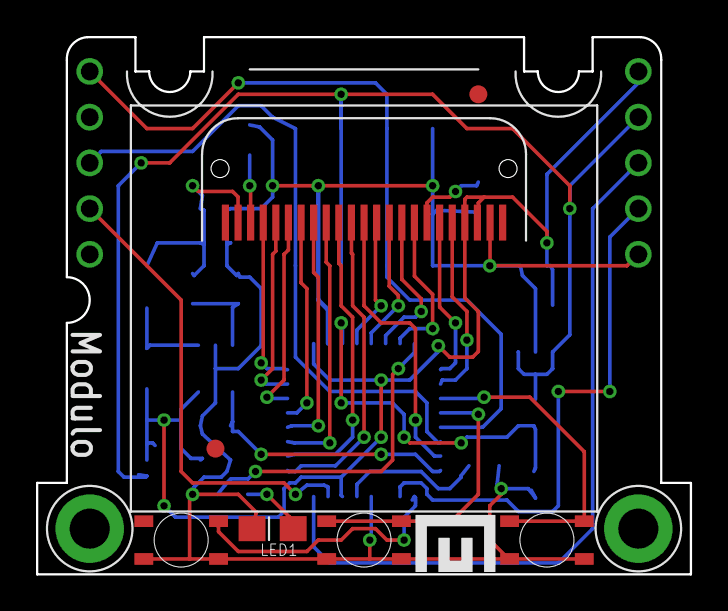
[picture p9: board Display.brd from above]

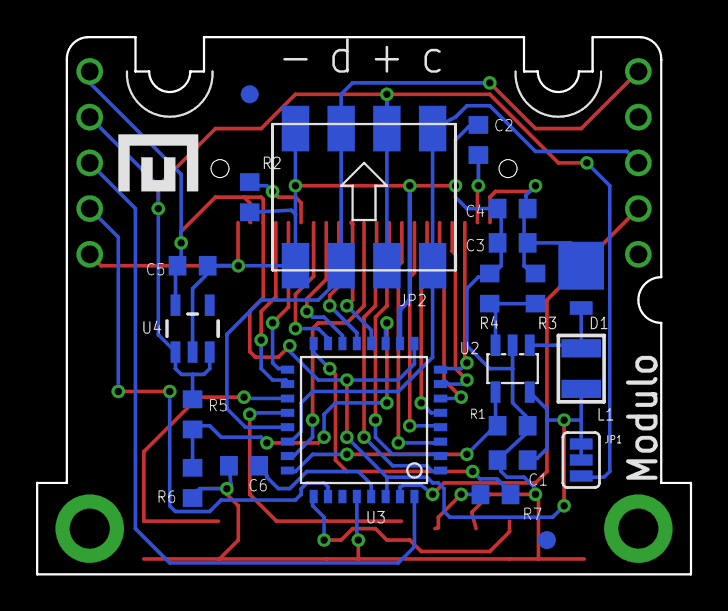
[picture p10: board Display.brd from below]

Board: 2 copper layers, 36.3 x 29.8 mm, 32 parts (23 on the bottom side), 36 nets.

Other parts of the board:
U$1, U$2: LOGO-SMALL

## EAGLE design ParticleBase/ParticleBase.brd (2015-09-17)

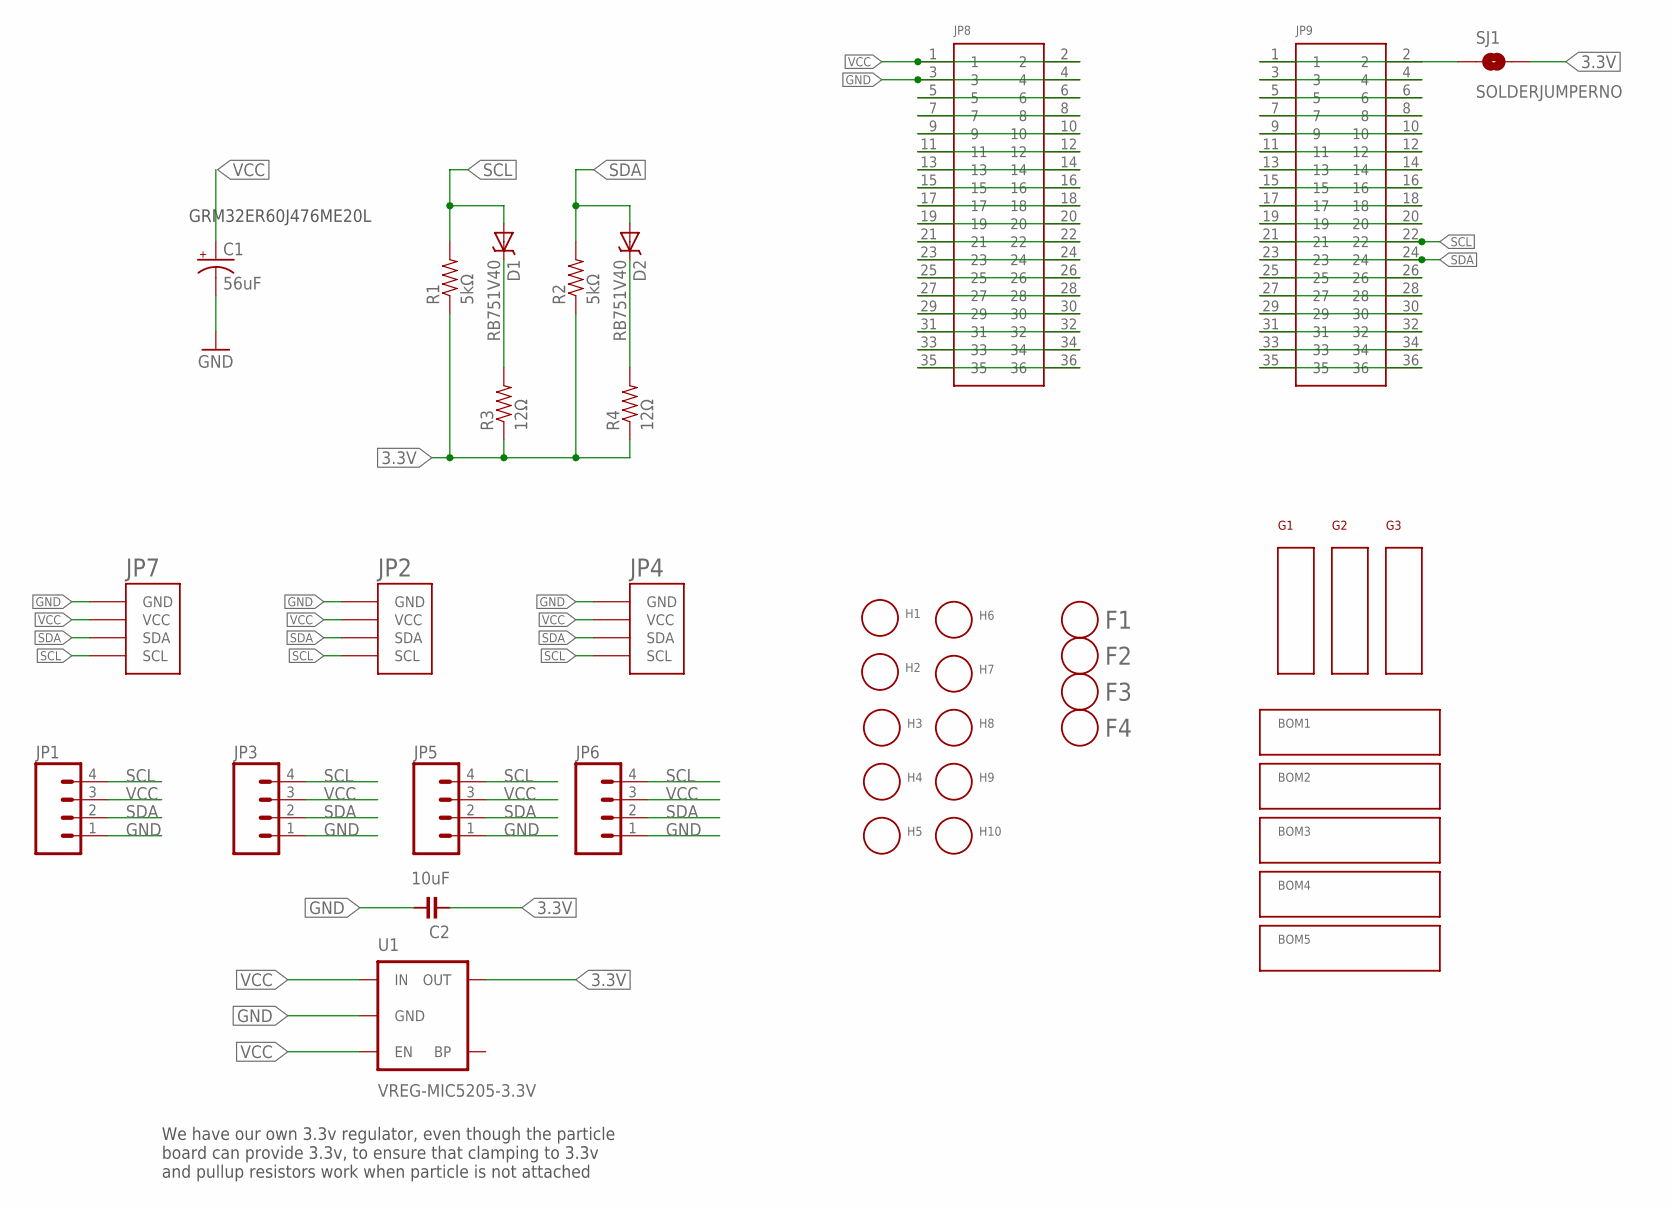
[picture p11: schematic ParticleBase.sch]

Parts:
C1: 56uF; PANASONIC_D
C2: 10uF; 0603
D1, D2: RB751V40; SOD-323; PARTNUM RB751V40
F1, F2, F3, F4: FIDUCIAL; FIDUCIAL_1MM
G1, G3: CARD-GUIDE; CARD-GUIDE-2; PARTNUM HCG-201-165
G2: CARD-GUIDE; CARD-GUIDE-2; PARTNUM HCG-202-165
H1, H2, H3, H4, H5, H6, H7, H8, H9, H10: HOLE#2; HOLE-#2
JP1, JP3, JP5, JP6: M04LOCK; 1X04_LOCK; PARTNUM M20-9750446
JP2, JP4, JP7: HEADER-MODULO; JST-PA-SIDE-SMD
JP8, JP9: HEADER-2X18; 2X18-LOCK; PARTNUM 12x2 Receptacle
R1, R2: 5kΩ; 0603
R3, R4: 12Ω; 0603
SJ1: SOLDERJUMPERNO; SJ_2S-NO
U1: VREG-MIC5205-3.3V; SOT23-5

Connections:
3.3V: C2.2, R1.1, R2.1, R3.1, R4.1, SJ1.2, U1.5 (OUT)
GND: C1.-, C2.1, JP1.1, JP2.1 (GND), JP3.1, JP4.1 (GND), JP5.1, JP6.1, JP7.1 (GND), JP8.3, JP8.4, U1.2 (GND)
unnamed: JP8.5, JP8.6
unnamed: JP8.7, JP8.8
unnamed: JP8.9, JP8.10
unnamed: JP8.11, JP8.12
unnamed: JP8.13, JP8.14
unnamed: JP8.15, JP8.16
unnamed: JP8.17, JP8.18
unnamed: JP8.19, JP8.20
unnamed: JP8.21, JP8.22
unnamed: JP8.23, JP8.24
unnamed: JP8.25, JP8.26
unnamed: JP8.27, JP8.28
unnamed: JP8.29, JP8.30
unnamed: JP9.5, JP9.6
unnamed: JP8.31, JP8.32
unnamed: D1.C, R3.2
unnamed: JP8.33, JP8.34
unnamed: JP8.35, JP8.36
unnamed: D2.C, R4.2
unnamed: JP9.3, JP9.4
unnamed: JP9.7, JP9.8
unnamed: JP9.9, JP9.10
unnamed: JP9.11, JP9.12
unnamed: JP9.13, JP9.14
unnamed: JP9.15, JP9.16
unnamed: JP9.17, JP9.18
unnamed: JP9.19, JP9.20
unnamed: JP9.25, JP9.26
unnamed: JP9.27, JP9.28
unnamed: JP9.29, JP9.30
unnamed: JP9.31, JP9.32
unnamed: JP9.33, JP9.34
unnamed: JP9.35, JP9.36
unnamed: JP9.1, JP9.2, SJ1.1
SCL: D1.A, JP1.4, JP2.4 (SCL), JP3.4, JP4.4 (SCL), JP5.4, JP6.4, JP7.4 (SCL), JP9.21, JP9.22, R1.2
SDA: D2.A, JP1.2, JP2.3 (SDA), JP3.2, JP4.3 (SDA), JP5.2, JP6.2, JP7.3 (SDA), JP9.23, JP9.24, R2.2
VCC: C1.+, JP1.3, JP2.2 (VCC), JP3.3, JP4.2 (VCC), JP5.3, JP6.3, JP7.2 (VCC), JP8.1, JP8.2, U1.1 (IN), U1.3 (EN)

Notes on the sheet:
GRM32ER60J476ME20L
We have our own 3.3v regulator, even though the particle board can provide 3.3v, to ensure that clamping to 3.3v and pullup resistors work when particle is not attached

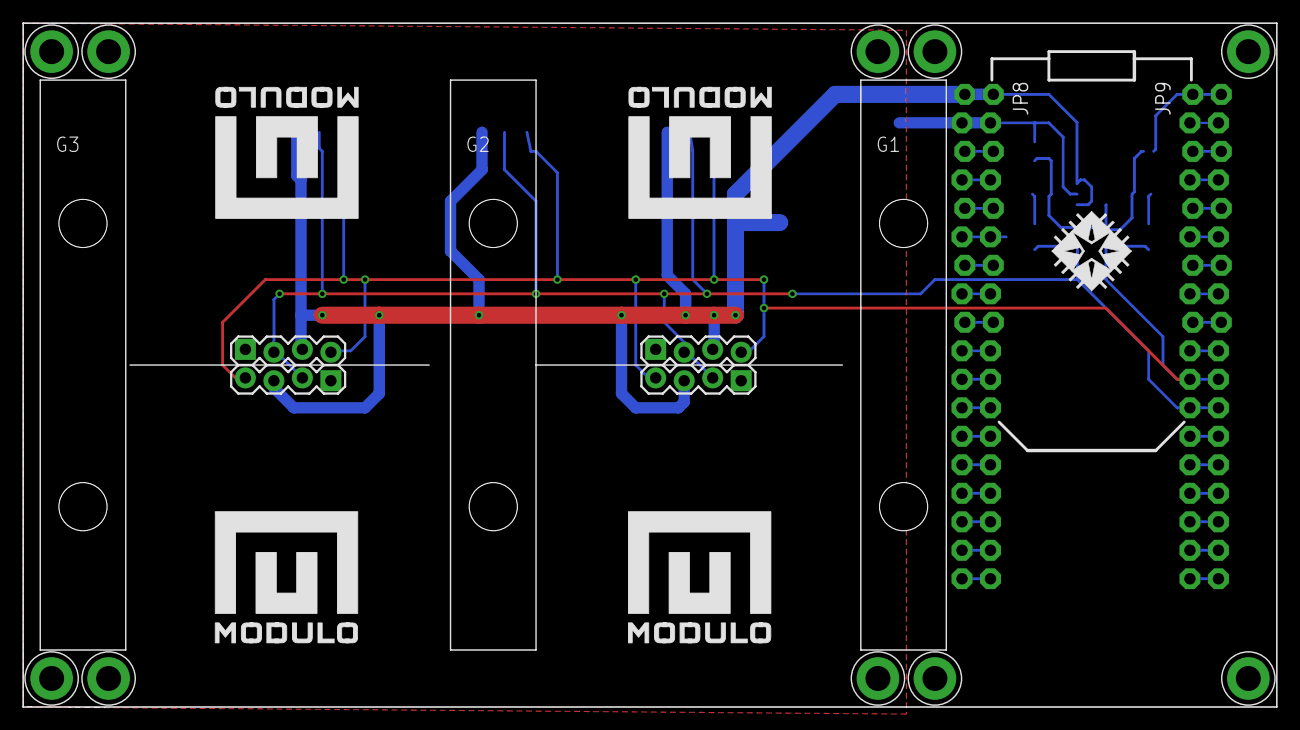
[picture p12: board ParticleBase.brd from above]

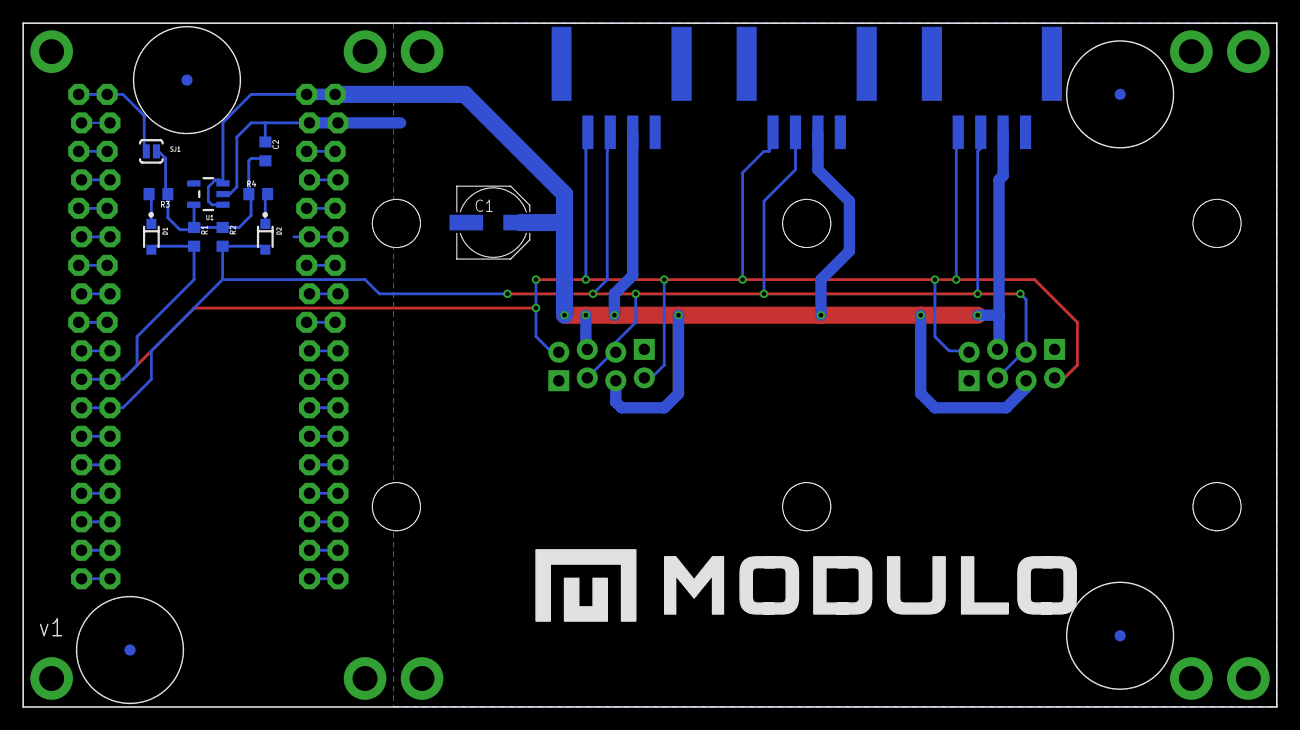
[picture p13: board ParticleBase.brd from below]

Board: 2 copper layers, 111.8 x 61.0 mm, 42 parts (18 on the bottom side), 39 nets.

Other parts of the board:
U$1, U$2, U$3, U$4: LOGO-0.5
U$5: LOGO-HOR-0.25
U$6: WORKS_WITH_PARTICLE_LOGO_LARGE

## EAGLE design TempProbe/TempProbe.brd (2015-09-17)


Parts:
C1, C2: .1uF; 0603
F1, F2, F3, F4: FIDUCIAL; FIDUCIAL_1MM
J1: AVR_SPI_PRG_6PTH; 2X3
JP2: M041X04_NO_SILK; 1X04_NO_SILK
LED1: blue; 0805-LED
PROBE1: TEMP-PROBE; TEMP_PROBE; PARTNUM NTCLE413E2103F102L
R1: 10KΩ; 0603
R2: 1KΩ; 0603
R8, R9: 0Ω; 0603
U2: ATTINY841; SOIC-14

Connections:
GND: C1.2, C2.1, J1.6, JP2.1, LED1.C, R1.1, U2.14 (GND)
MISO/LED: J1.1, R2.2, U2.8 (PA5)
unnamed: LED1.A, R2.1
RESET: J1.5, U2.4 (PB3)
SCL: JP2.4, R8.1
SCL/SCK: J1.3, R8.2, U2.9 (PA4)
SDA: JP2.3, R9.1
SDA/MOSI: J1.4, R9.2, U2.7 (PA6)
TEMP: C2.2, PROBE1.P$1 (+), R1.2, U2.2 (PB0)
VCC: C1.1, J1.2, JP2.2, PROBE1.P$2 (-), U2.1 (VCC)



Board: 2 copper layers, 23.5 x 12.7 mm, 16 parts (8 on the bottom side), 10 nets.

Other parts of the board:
U$1: LOGO-TINY

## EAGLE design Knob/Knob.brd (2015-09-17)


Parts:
C1: .1uF; 0603
F1, F2: FIDUCIAL; FIDUCIAL_1MM
JP1: HEADER-1X4-AMPMODU; AMPMODU-4P
LED1: LED-1206-REV
PCB1: DEVICE-PCB; PARTNUM Knob PCB
R1, R7: 1KΩ; 0603
R2, R3, R4, R5, R6, R10: 150Ω; 0603
R8, R9: 0Ω; 0603
SW1: TopUp EC12PLRGBSDVBF-D; ENCODER_LED_3_SIDEPADS; PARTNUM TopUp EC12PLRGBSDVBF-D
U2: ATTINY841; SOIC-14

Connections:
A: SW1.A, U2.3 (PB1)
B: SW1.B, U2.2 (PB0)
BLUE: R5.2, R6.2, U2.5 (PB2)
GND: C1.2, JP1.P$1 (1), JP1.P$2 (1), LED1.C, PCB1.GND, R1.2, SW1.C, U2.14 (GND)
GREEN: R3.2, R4.2, U2.6 (PA7)
MISO/LED: PCB1.MISO, R7.2, U2.8 (PA5)
unnamed: R2.1, R10.1, SW1.1 (-R)
unnamed: R3.1, R4.1, SW1.2 (-G)
unnamed: R5.1, R6.1, SW1.4 (-B)
unnamed: LED1.A, R7.1
RED: R2.2, R10.2, U2.12 (PA1)
RESET: PCB1.RESET, U2.4 (PB3)
SCL: JP1.P$7 (4), JP1.P$8 (4), PCB1.CLK (SCK), PCB1.SCL, R8.1
SCL/SCK: R8.2, U2.9 (PA4)
SDA: JP1.P$3 (2), JP1.P$4 (2), PCB1.MOSI, PCB1.SDA, R9.1
SDA/MOSI: R9.2, U2.7 (PA6)
SW: R1.1, SW1.3 (SW), U2.11 (PA2)
VCC: C1.1, JP1.P$5 (3), JP1.P$6 (3), PCB1.VCC, PCB1.VPROG, SW1.5 (+), U2.1 (VCC)



Board: 2 copper layers, 36.3 x 29.8 mm, 20 parts (17 on the bottom side), 18 nets.

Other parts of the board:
U$2, U$3: LOGO-SMALL

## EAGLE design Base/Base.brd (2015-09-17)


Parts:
C1: 10uF; 0603
D1, D2: RB751V40; SOD-323; PARTNUM RB751V40
F1, F2: FIDUCIAL; FIDUCIAL_1MM
G1, G3: CARD-GUIDE; CARD-GUIDE-2; PARTNUM HCG-201-165
G2: CARD-GUIDE; CARD-GUIDE-2; PARTNUM HCG-202-165
H1, H2, H3, H4, H5, H6, H7, H8: HOLE#2; HOLE-#2
JP1, JP3, JP5, JP6: M04LOCK; 1X04_LOCK; PARTNUM M20-9750446
JP2, JP4, JP7: HEADER-MODULO; JST-PA-SIDE-SMD
R1, R2: 12Ω; 0603
R3, R4: 5kΩ; 0603
U1: VREG-MIC5205-3.3V; SOT23-5

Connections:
3.3V: C1.1, R1.2, R2.2, R3.2, R4.2, U1.5 (OUT)
GND: C1.2, JP1.1, JP2.1 (GND), JP3.1, JP4.1 (GND), JP5.1, JP6.1, JP7.1 (GND), U1.2 (GND)
unnamed: D2.C, R2.1
unnamed: D1.C, R1.1
SCL: D2.A, JP1.4, JP2.4 (SCL), JP3.4, JP4.4 (SCL), JP5.4, JP6.4, JP7.4 (SCL), R3.1
SDA: D1.A, JP1.2, JP2.3 (SDA), JP3.2, JP4.3 (SDA), JP5.2, JP6.2, JP7.3 (SDA), R4.1
VCC: JP1.3, JP2.2 (VCC), JP3.3, JP4.2 (VCC), JP5.3, JP6.3, JP7.2 (VCC), U1.1 (IN), U1.3 (EN)



Board: 2 copper layers, 83.8 x 61.0 mm, 33 parts (14 on the bottom side), 7 nets.

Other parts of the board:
U$1: LOGO-HOR-0.25
U$3, U$4, U$5, U$6: LOGO-0.5

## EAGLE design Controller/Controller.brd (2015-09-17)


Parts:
C1, C6, C9: 10uF; 0603
C2, C3: 18pF; 0603
C4, C7, C8: .1uF; 0603
C5: 56uF; PANASONIC_D
D1: DIODE-SCHOTTKY; SMP
D2, D3, D4, D5, D6, D7: DIODE-SCHOTTKY-BAT60A; SOD-323; PARTNUM RB751V40
F1, F2, F3, F4: FIDUCIAL; FIDUCIAL_1MM
JP1: USBFCI-MICROB; USB-MICROB-FCI; PARTNUM 10118193-0001LF
JP2: HEADER-1X4-AMPMODU; AMPMODU-4P
JP3, JP4, JP5: PINHD-1X6LOCK; 1X06-BIGLOCK; PARTNUM M20-9990646
JP6: M02LOCK; 1X02_LOCK; PARTNUM M20-9990246
L1: 10uH; 0603; PARTNUM BLM18TG102TN1D
LED1: blue; 0805-LED; PARTNUM LTST-C171KRKT
LED2: blue; 0805-LED
PCB1: DEVICE-PCB; PARTNUM Controller PCB
R1, R2: 5kΩ; 0603
R3, R4, R5, R6, R7, R8: 470Ω; 0603
R9, R10: 1KΩ; 0603
SW1: SWITCH-PTS-810; TACT-SWITCH-PTS-810
U1: ATSAMD21E18A-AU; TQFP-32; PARTNUM ATSAMD21E18A-AUT
U2: VREG-MIC5205-3.3V; SOT23-5; PARTNUM MIC5205-3.3YM5 TR
X1: CRYSTAL-AB26TRQ-32.768K; CRYSTAL-AB26TRQ

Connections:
+3.3V: C8.1, C9.1, D2.C, D3.C, D4.C, D5.C, D6.C, D7.C, JP6.1, L1.1, LED1.A, PCB1.VPROG, R1.1, R2.1, U1.30 (VDDIN), U2.5 (OUT)
D+: JP1.P3 (D+), U1.24 (PA25)
D-: JP1.P2 (D-), U1.23 (PA24)
GND: C1.2, C2.1, C3.1, C4.2, C5.-, C6.2, C7.2, C8.2, C9.2, JP1.P5 (GND), JP2.P$1 (1), JP2.P$2 (1), JP4.1, JP4.2, JP4.3, JP4.4, JP4.5, JP4.6, JP6.2, PCB1.GND, R9.1, R10.1, SW1.P$3 (NEG1), SW1.P$4 (NEG1), U1.10 (GNDANA), U1.28 (GND), U2.2 (GND)
IO0: D7.A, R8.1, U1.3 (PA02)
IO1: D6.A, R7.1, U1.4 (PA03)
IO2: D5.A, R6.1, U1.5 (PA04)
IO3: D4.A, R5.1, U1.6 (PA05)
IO4: D3.A, R4.1, U1.7 (PA06)
IO5: D2.A, R3.1, U1.8 (PA07)
LED: LED2.A, U1.17 (PA16)
unnamed: LED1.C, R9.2
unnamed: JP3.1, R3.2
unnamed: D1.A, JP1.P1 (VBUS)
unnamed: LED2.C, R10.2
unnamed: C2.2, U1.1 (PA00), X1.XOUT (X2)
unnamed: C3.2, U1.2 (PA01), X1.XIN (X1)
unnamed: JP3.2, R4.2
unnamed: JP3.3, R5.2
unnamed: JP3.4, R6.2
unnamed: JP3.5, R7.2
unnamed: JP3.6, R8.2
unnamed: C1.1, C4.1, L1.2, U1.9 (VDDANA)
unnamed: C7.1, U1.29 (VDDCORE)
N_HOST_ENABLE: JP1.P4 (ID), U1.27 (PA28)
RESET: PCB1.RESET, SW1.P$1 (POS1), SW1.P$2 (POS1), U1.26 (RESETN)
SCL: JP2.P$7 (4), JP2.P$8 (4), PCB1.SCL, R1.2, U1.12 (PA09)
SDA: JP2.P$3 (2), JP2.P$4 (2), PCB1.SDA, R2.2, U1.11 (PA08)
SWCLK: PCB1.CLK (SCK), U1.31 (PA30)
SWDIO: PCB1.SWDIO, U1.32 (PA31)
VCC: C5.+, C6.1, D1.C, JP2.P$5 (3), JP2.P$6 (3), JP5.1, JP5.2, JP5.3, JP5.4, JP5.5, JP5.6, PCB1.VCC, U2.1 (IN), U2.3 (EN)

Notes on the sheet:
max source/sink current for sum of all I/O pins in cluster is 46ma/65ma.



Board: 2 copper layers, 36.3 x 29.8 mm, 45 parts (26 on the bottom side), 31 nets.

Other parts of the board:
U$2: LOGO-TINY

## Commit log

2014-06-20 Initial versions of a bunch of boards
    [A4980.brd, A4980.sch, DRV8834.brd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]
2014-08-20 Checking in current version of OLED board
    [OLED.brd, OLED.sch]
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2014-08-22 GPIO board rebuilt for v2 footprint
    [GPIO.brd, GPIO.sch]
2014-08-27 Added current limiting resistors to io pins
    [GPIO.brd, GPIO.sch]
2014-08-30 Ruggedized GPIO board with current limiting resistors and clamping diodes.
    [GPIO.brd, GPIO.sch]
2014-08-30 New OLED design for v2 footprint.
    [OLED.brd, OLED.sch]
2014-08-30 New programmer/hub board with guide rails for v2 footprint.
    [Programmer.brd, Programmer.sch]
2014-08-30 New motor driver board based on the NJM2670 chip.
    [NJM2670.brd, NJM2670.sch]
2014-08-30 New arduino leonardo compatible board based on the ATmega32u4.
    [32u4.brd, 32u4.sch]
2014-08-30 BitButton board which works with the SparkFun elastomer button pad
    [BigButton.brd, BigButton.sch]
2014-08-30 Mostly re-routed the TB6612FNG based motor driver board for the v2 footprint. Not finished, since I'm planning to abandon this chip.
    [TB6612FNG.brd, TB6612FNG.sch]
2014-08-30 Latest version of NavButtons
    [NavButtons.brd, NavButtons.sch]
2014-08-30 Microcontroller board for the SAMD21 chip.
    [SAMD21.brd, SAMD21.sch]
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2014-08-30 Small thermistor board. Doesn't use modulo footprint, but instead is designed to be an inline/remote sensor.
    [Thermistor.brd, Thermistor.sch]
2014-08-30 Cleaned up pcb repository file structure.
    [A4980.brd, A4980.sch, DRV8834.brd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]
2014-09-08 Changed OLED board to use ATmega328P instead of ATtiny841.
    [OLED.brd, OLED.sch]
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2014-10-15 Latest version of schematics and boards
    [32u4.brd, 32u4.sch, AC.brd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]
2014-11-22 Changed NavButtons back to using attiny441
    [NavButtons.brd, NavButtons.sch]
2014-11-22 New linear/inline layout of motor driver board
    [NJM2670.brd, NJM2670.sch]
2014-11-22 Reverted to old version of motor driver board
    [NJM2670.brd, NJM2670.sch]
2014-11-24 OLED: added buttons and rewired for attiny841 Thermocouple: checkpoint of latest version with two amplifiers and attiny48
    [OLED.brd, OLED.sch, Thermocouple.brd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]
2014-11-25 New thermocouple revision with single input and quick connect terminals
    [Thermocouple.brd, Thermocouple.sch]
2014-11-25 Changed to use attiny841
    [NavButtons.brd, NavButtons.sch]
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2014-12-22 New 32u4 controller board with servo pin compatible gpio and RPi reverse current protection.
    [32u4.brd, 32u4.sch]
2014-12-22 New Hub with smaller form factor and bus connectors on bottom.
    [Hub.brd, Hub.sch]
2014-12-22 Updated footprint and swich, instead of jumper, for selecting output voltage.
    [NJM2670.brd, NJM2670.sch]
2014-12-22 Switched to attiny841 and made the battery insert from the side.
    [RTC.brd, RTC.sch]
2014-12-22 New versions of IntegerLabs library, RotaryEncoder, and Thermocouple
    [RotaryEncoder.brd, RotaryEncoder.sch, Thermocouple.brd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]
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2014-12-22 New switching power supply board
    [PowerSupply.brd, PowerSupply.sch]
2014-12-22 New Raspberry Pi Adapter Board
    [RPi.brd, RPi.sch]
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2015-06-10 Renamed 32u4 to Controller
    [Controller.brd, Controller.sch]
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2015-06-10 Moved a bunch of files around
    [AC.brd, AC.sch, Adapter.sch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]
2015-07-09 Major revision of all boards. Cleaned up old files. Exported BOM csv files for all boards
    [Base.brd, Base.csv, Base.sch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]
2015-07-09 Part details spread sheet and script to consolidate BOMs for all boards into a single BOM.
    [ConsolidatedBOM.csv, PartDetails.csv]
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2015-07-22 Added knob cap BOM item
    [Knob.csv, Knob.sch]
2015-07-22 Switched to side entry connectors
    [ParticleBase.brd, ParticleBase.csv, ParticleBase.sch]
2015-07-28 Fixed a missing connection.
    [Display.brd, Display.sch]
2015-08-15 New scripts that combine and panelize boards, boms, and centroid data.
    [PartDetails.csv, bom.csv, centroid.csv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]
2015-08-15 Revised temperature probe layout and created new temp probe programmer board
    [TempProbeProgrammer.brd, TempProbeProgrammer.sch]
2015-08-15 Fixed bad clamp diode wiring and added a reverse protection diode
    [Controller.brd, Controller.sch]
2015-08-15 Check point of current PCB designs. Among other things I think this change includes rewiring of programming lines on many of the boards,.
    [Base.brd, Base.sch, BlankSlate.brd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]
2015-08-18 Fixed missing trace on SCL/SCK net.
    [Knob.brd]
2015-08-19 Added parallel resistor on red channel for better white balance. Moved status LED to opposite side of the board next to logo Updated to new 0603 footprint.
    [Knob.brd, Knob.sch]
2015-08-19 Added 3.3V regulator and solder jump to select operating voltage 10mil traces instead of 8 swapped I/O pins 3 and 4 so that PWM capable pins are contiguous moved the status LED so that it's next to t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
    [BlankSlate.brd, BlankSlate.sch]
2015-08-19 Increased trace width to 10mil from 8 Bumped version number to 6
    [Knob.brd]
2015-08-19 Moved logo near LED Bumped version number Increased trace widths from 8mil to 10mil tented vias
    [Joystick.brd]
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2015-08-20 Fixed 3.3V connection. The old pin worked with the Spark but not the Photon.
    [ParticleBase.brd, ParticleBase.sch]
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2015-08-21 Changed to use direct wire soldering for modulo bus instead of a connector.
    [TempProbe.brd, TempProbe.sch]
2015-09-07 Tented vias Updated extension cable connectors Added 3.3v regulator and clamping diodes
    [Base.brd, Base.sch]
2015-09-07 Fixed PARTNUM on 3.3v regulator.
    [BlankSlate.brd, BlankSlate.sch]
2015-09-07 Various fixes
    [Display.brd, Display.sch]
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2015-09-11 Various small tweaks based on testing and feedback from manufacturer.
    [Base.bom.csv, Base.brd, Base.centroid.csv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]
2015-09-17 Various minor tweaks based on testing and feedback from manufacturer
    [Base.brd, BlankSlate.brd, Controller.brd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]
2015-09-17 New fiducial "board" for use by the panelization script
    [Fiducial.bom.csv, Fiducial.brd, Fiducial.centroid.csv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]
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2018-09-04 updated cam for Eagle 9 exported files for BlankSlate removed unused files '
    [BlankSlate.brd, BlankSlate.csv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]
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

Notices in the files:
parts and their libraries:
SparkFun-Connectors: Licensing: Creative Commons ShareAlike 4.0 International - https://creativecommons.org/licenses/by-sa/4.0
